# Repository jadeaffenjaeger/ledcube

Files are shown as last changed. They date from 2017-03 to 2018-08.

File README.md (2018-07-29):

# Contents
Codebase and Schematics for an easily extendable LED cube based on the STM32F103 and TPIC6B595 shift registers.

## Structure
The cube uses two types of driver PCBs: One *Level driver*, which activates the anodes for one out of eight levels at a time. The PCB also contains the main MCU on a "Blue Pill" breakout board, as well as voltage regulation for the MCU and 74HCT245 bus driver for 3.3V-5V level conversion.
Four *Row Drivers*, each of which controls the anodes of 16 of 64 columns independently.
All boards are designed to be chained together with the level driver coming first, followed by the row drivers.
This makes it possible to control the cube with just 3 pins on the MCU. All boards are designed to be extendable and reusable for cubes that require more or less contol pins

## Row Driver Boards
The driver board contains two TPIC6B595, capable of controlling a total of 16 outputs with a current sinking capability of 100mA per channel, eliminating the need for external driving transistors. Resistors can be replaced easily to allow for different types of LEDs. The boards are designed to be daisy-chained together, so that larger cubes can be built without redesigning anything, just by adding more driver boards. Also, this easily fills up the minimum order with most board houses. I had mine
manufactured at [Dirty PCBs](www.dirtypcbs.com), where 10 boards cost around 15USD.

Inputs on the board are:

    1 VCC
    2 Serial Clock
    3 Register Clock/Latch
    4 Serial Data
    5 GND

Assembled Board:
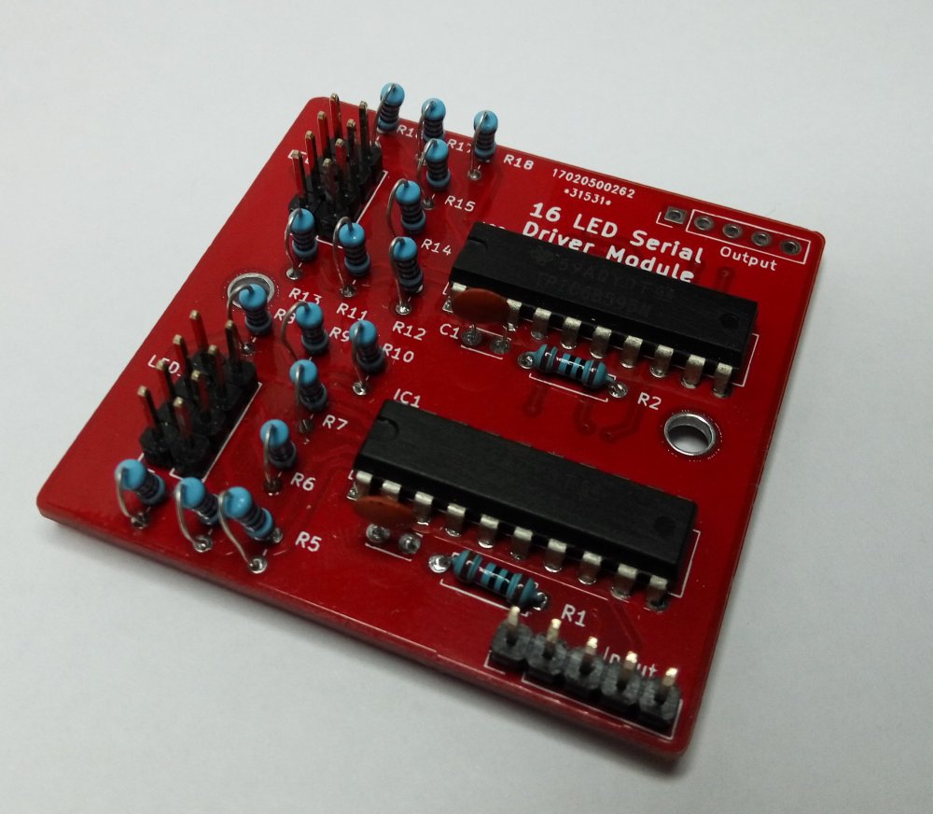
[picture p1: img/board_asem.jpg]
Assembled Driver Board


## Level Driver board
In an earlier iteration, this was a very simple board that only contained the shift register IC and the p-channel MOSFETs. As of now, the board was redesigned to contain the MCU, voltage regulation and the shift register and MOS transistors

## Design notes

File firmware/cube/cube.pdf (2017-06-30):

## cube Project Configuration Report

# 1. Description

## 1.1. Project

Project Name | cube
Board Name | cube
Generated with: | STM32CubeMX 4.21.0
Date | 06/29/2017

## 1.2. MCU

MCU Series | STM32F1
MCU Line | STM32F103
MCU name | STM32F103C8Tx
MCU Package | LQFP48
MCU Pin number | 48

# 2. Pinout Configuration

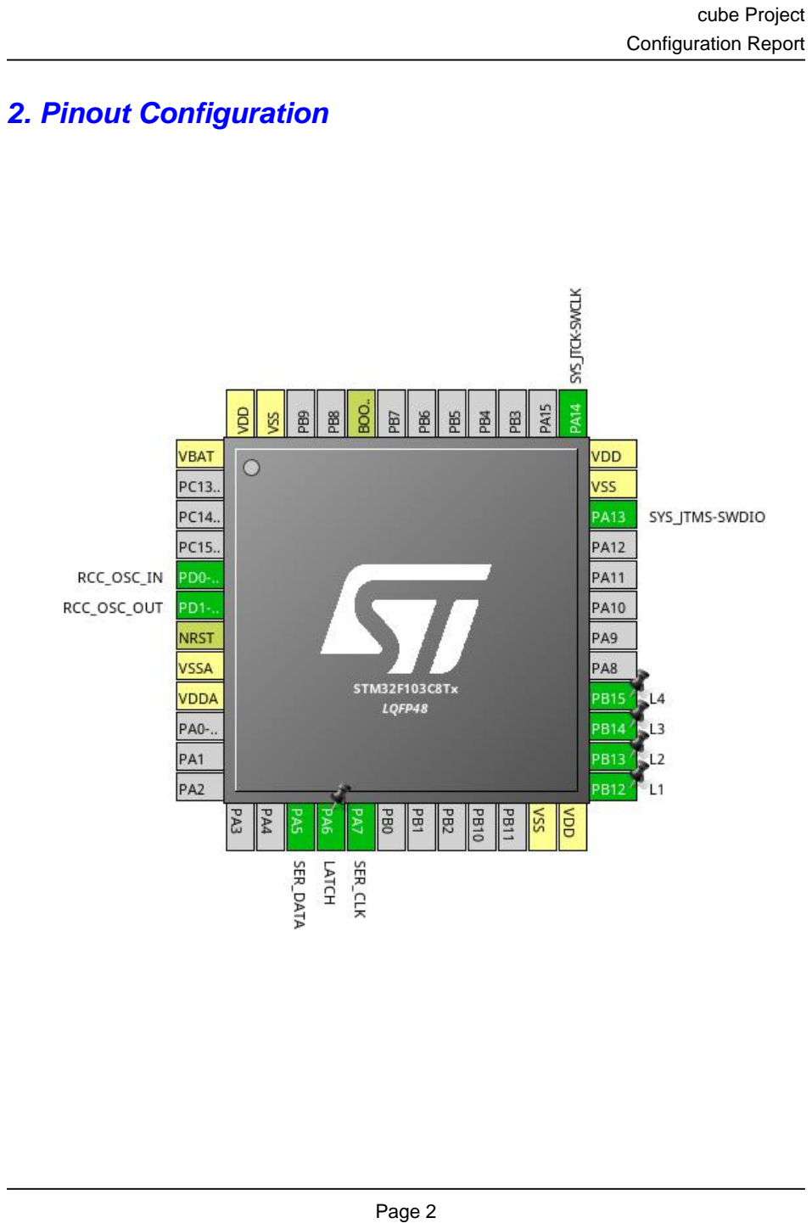
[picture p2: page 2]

# 3. Pins Configuration

Pin Number LQFP48 | Pin Name (function after reset) | Pin Type | Alternate Function(s) | Label
1 | VBAT | Power
5 | PD0-OSC_IN | I/O | RCC_OSC_IN
6 | PD1-OSC_OUT | I/O | RCC_OSC_OUT
7 | NRST | Reset
8 | VSSA | Power
9 | VDDA | Power
15 | PA5 | I/O | SPI1_SCK | SER_DATA
16 | PA6 * | I/O | GPIO_Output | LATCH
17 | PA7 | I/O | SPI1_MOSI | SER_CLK
23 | VSS | Power
24 | VDD | Power
25 | PB12 * | I/O | GPIO_Output | L1
26 | PB13 * | I/O | GPIO_Output | L2
27 | PB14 * | I/O | GPIO_Output | L3
28 | PB15 * | I/O | GPIO_Output | L4
34 | PA13 | I/O | SYS_JTMS-SWDIO
35 | VSS | Power
36 | VDD | Power
37 | PA14 | I/O | SYS_JTCK-SWCLK
44 | BOOT0 | Boot
47 | VSS | Power
48 | VDD | Power

## * The pin is affected with an I/O function

# 4. Clock Tree Configuration

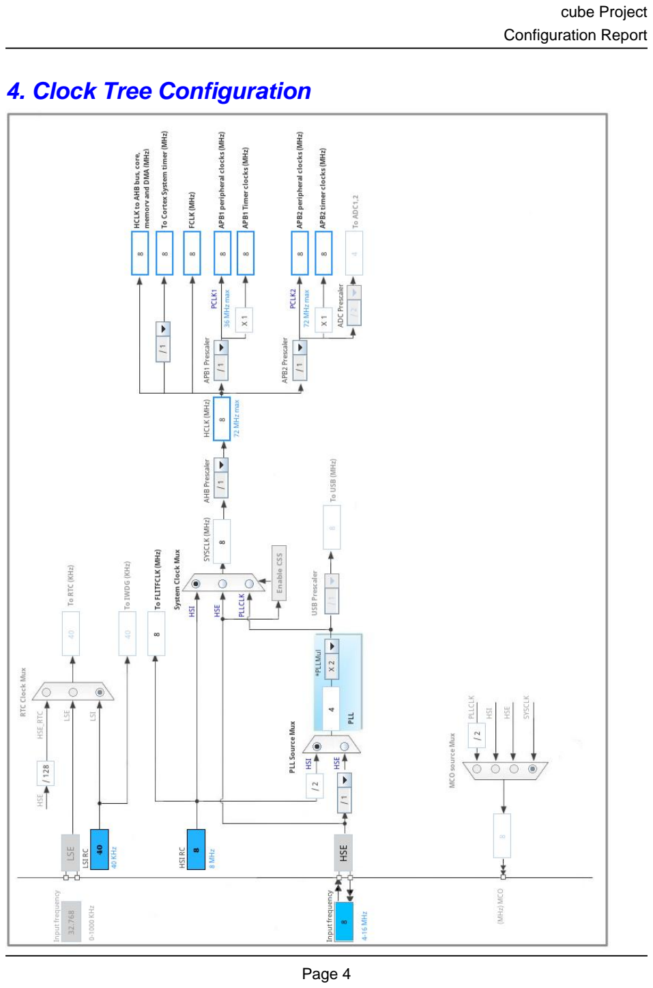
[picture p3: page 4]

# 5. IPs and Middleware Configuration

# 5.1. RCC

## High Speed Clock (HSE): Crystal/Ceramic Resonator

## 5.1.1. Parameter Settings:

### System Parameters:

VDD voltage (V) | 3.3
Prefetch Buffer | Enabled
Flash Latency(WS) | 0 WS (1 CPU cycle)

### RCC Parameters:

HSI Calibration Value | 16
HSE Startup Timout Value (ms) | 100
LSE Startup Timout Value (ms) | 5000

# 5.2. SPI1

## Mode: Transmit Only Master

## 5.2.1. Parameter Settings:

### Basic Parameters:

Frame Format | Motorola
Data Size | 8 Bits
First Bit | MSB First

### Clock Parameters:

Prescaler (for Baud Rate) | 2
Baud Rate | 4.0 MBits/s *
Clock Polarity (CPOL) | Low
Clock Phase (CPHA) | 1 Edge

### Advanced Parameters:

CRC Calculation | Disabled
NSS Signal Type | Software

# 5.3. SYS

## Debug: Serial Wire Timebase Source: SysTick

# 5.4. TIM2

## Clock Source : Internal Clock

## 5.4.1. Parameter Settings:

### Counter Settings:

Prescaler (PSC - 16 bits value) | 0
Counter Mode | Up
Counter Period (AutoReload Register - 16 bits value ) | 0
Internal Clock Division (CKD) | No Division

### Trigger Output (TRGO) Parameters:

Master/Slave Mode | Disable (no sync between this TIM (Master) and its Slaves
Trigger Event Selection | Reset (UG bit from TIMx_EGR)

### * User modified value

# 6. System Configuration

# 6.1. GPIO configuration

IP | Pin | Signal | GPIO mode | GPIO pull/up pull down | Max Speed | User Label
RCC | PD0-OSC_IN | RCC_OSC_IN | n/a | n/a | n/a
| PD1-OSC_OUT | RCC_OSC_OUT | n/a | n/a | n/a
SPI1 | PA5 | SPI1_SCK | Alternate Function Push Pull | n/a | High * | SER_DATA
| PA7 | SPI1_MOSI | Alternate Function Push Pull | n/a | High * | SER_CLK
SYS | PA13 | SYS_JTMS-SWDIO | n/a | n/a | n/a
| PA14 | SYS_JTCK-SWCLK | n/a | n/a | n/a
GPIO | PA6 | GPIO_Output | Output Push Pull | n/a | Low | LATCH
| PB12 | GPIO_Output | Output Push Pull | n/a | Low | L1
| PB13 | GPIO_Output | Output Push Pull | n/a | Low | L2
| PB14 | GPIO_Output | Output Push Pull | n/a | Low | L3
| PB15 | GPIO_Output | Output Push Pull | n/a | Low | L4

# 6.2. DMA configuration

DMA request | Stream | Direction | Priority
SPI1_TX | DMA1_Channel3 | Memory To Peripheral | Low

## SPI1_TX: DMA1_Channel3 DMA request Settings:

Mode: | Normal
Peripheral Increment: | Disable
Memory Increment: | Enable *
Peripheral Data Width: | Byte
Memory Data Width: | Byte

# 6.3. NVIC configuration

Interrupt Table | Enable | Preenmption Priority | SubPriority
Non maskable interrupt | true | 0 | 0
Hard fault interrupt | true | 0 | 0
Memory management fault | true | 0 | 0
Prefetch fault, memory access fault | true | 0 | 0
Undefined instruction or illegal state | true | 0 | 0
System service call via SWI instruction | true | 0 | 0
Debug monitor | true | 0 | 0
Pendable request for system service | true | 0 | 0
System tick timer | true | 0 | 0
DMA1 channel3 global interrupt | true | 0 | 0
TIM2 global interrupt | true | 0 | 0
SPI1 global interrupt | true | 0 | 0
PVD interrupt through EXTI line 16 | unused
Flash global interrupt | unused
RCC global interrupt | unused

### * User modified value

# 7. Power Consumption Calculator report

### 7.1. Microcontroller Selection

Series | STM32F1
Line | STM32F103
MCU | STM32F103C8Tx
Datasheet | 13587_Rev17

### 7.2. Parameter Selection

Temperature | 25
Vdd | 3.3

# 8. Software Project

## 8.1. Project Settings

Name | Value
Project Name | cube
Project Folder | /home/elias/ledcube/firmware/cube
Toolchain / IDE | Makefile
Firmware Package Name and Version | STM32Cube FW_F1 V1.4.0

## 8.2. Code Generation Settings

Name | Value
STM32Cube Firmware Library Package | Copy only the necessary library files
Generate peripheral initialization as a pair of '.c/.h' files | Yes
Backup previously generated files when re-generating | No
Delete previously generated files when not re-generated | Yes
Set all free pins as analog (to optimize the power consumption) | No

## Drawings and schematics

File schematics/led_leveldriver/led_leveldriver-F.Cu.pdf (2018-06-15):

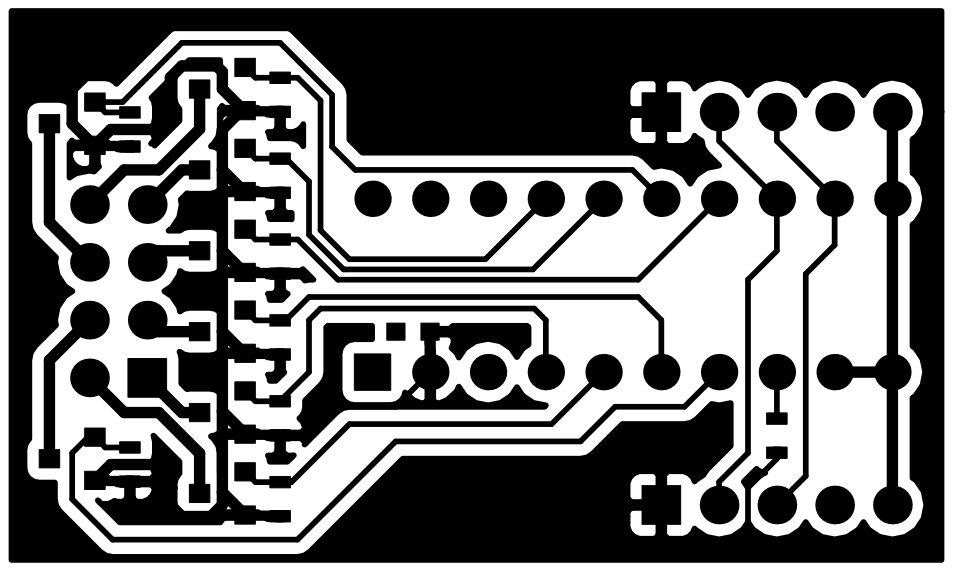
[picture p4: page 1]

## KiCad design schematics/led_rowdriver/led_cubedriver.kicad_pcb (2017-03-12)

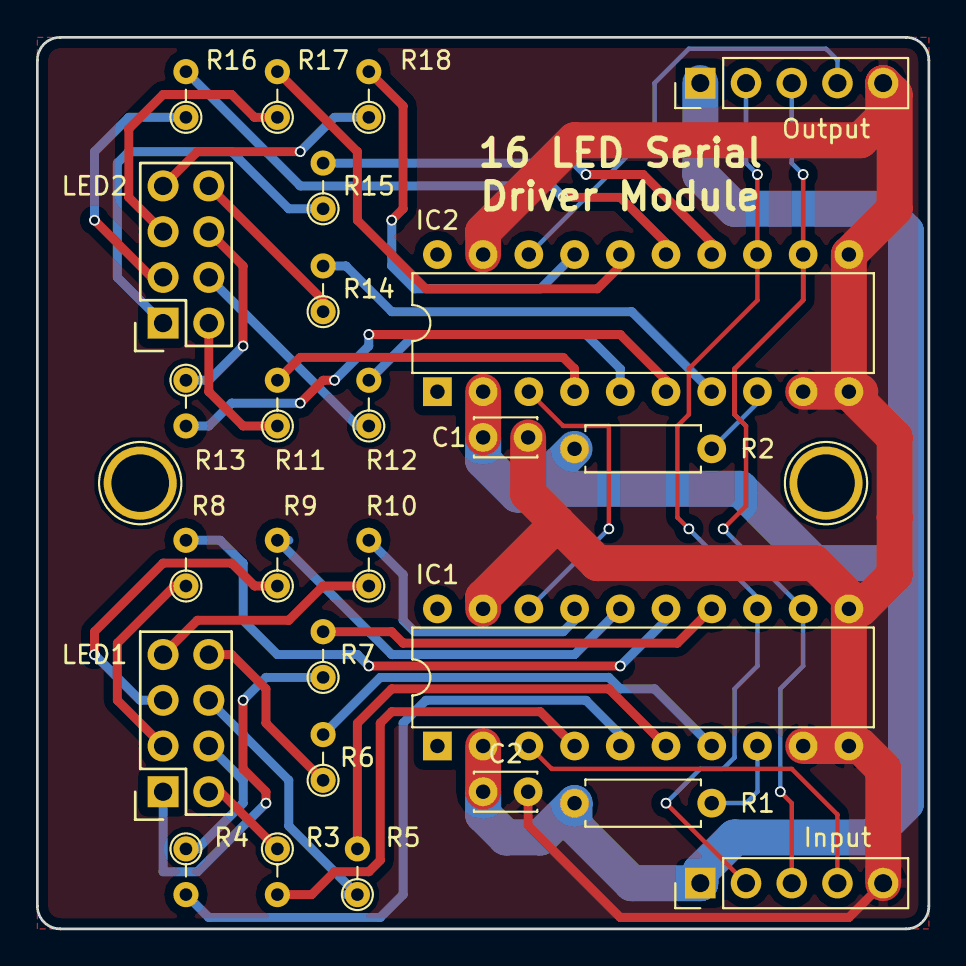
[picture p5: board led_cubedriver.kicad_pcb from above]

Board: 2 copper layers, 49.5 x 49.5 mm, 26 parts (0 on the bottom side), 41 nets.

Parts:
C1, C2: 0.1uF; C_Disc_D3.4mm_W2.1mm_P2.50mm
IC1, IC2: TPIC6B595; DIP-20_W7.62mm
Input: CONN_01X05; Pin_Header_Straight_1x05_Pitch2.54mm
LED1, LED2: CONN_02X04; Socket_Strip_Straight_2x04
Output: CONN_01X05; Pin_Header_Straight_1x05_Pitch2.54mm
R1, R2: 10k; R_Axial_DIN0207_L6.3mm_D2.5mm_P7.62mm_Horizontal
R3, R4, R5, R6, R7, R8, R9, R10, R11, R12, R13, R14, R15, R16, R17, R18: 100; R_Axial_DIN0204_L3.6mm_D1.6mm_P2.54mm_Vertical

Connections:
/RCK: IC1.12, IC2.12, Input.3, Output.3
/SRCK: IC1.13, IC2.13, Input.2, Output.2
GND: C1.2, C2.2, IC1.9, IC1.10, IC1.11, IC1.19, IC2.9, IC2.10, IC2.11, IC2.19, Input.5, Output.5
unnamed: IC1.3, Input.4
unnamed: IC2.18, Output.4
unnamed: IC1.4, R3.2
unnamed: IC1.5, R4.2
unnamed: IC1.6, R5.2
unnamed: IC1.7, R6.2
unnamed: IC1.8, R1.1
unnamed: IC1.14, R7.2
unnamed: IC1.15, R8.2
unnamed: IC1.16, R9.2
unnamed: IC1.17, R10.2
unnamed: IC1.18, IC2.3
unnamed: IC2.4, R11.2
unnamed: IC2.5, R12.2
unnamed: IC2.6, R13.2
unnamed: IC2.7, R14.2
unnamed: IC2.8, R2.1
unnamed: IC2.14, R15.2
unnamed: IC2.15, R16.2
unnamed: IC2.16, R17.2
unnamed: IC2.17, R18.2
unnamed: LED1.1, R7.1
unnamed: LED1.2, R3.1
unnamed: LED1.3, R8.1
unnamed: LED1.4, R4.1
unnamed: LED1.5, R9.1
unnamed: LED1.6, R5.1
unnamed: LED1.7, R10.1
unnamed: LED1.8, R6.1
unnamed: LED2.1, R15.1
unnamed: LED2.2, R11.1
unnamed: LED2.3, R16.1
unnamed: LED2.4, R12.1
unnamed: LED2.5, R17.1
unnamed: LED2.6, R13.1
unnamed: LED2.7, R18.1
unnamed: LED2.8, R14.1
VCC: C1.1, C2.1, IC1.2, IC2.2, Input.1, Output.1, R1.2, R2.2

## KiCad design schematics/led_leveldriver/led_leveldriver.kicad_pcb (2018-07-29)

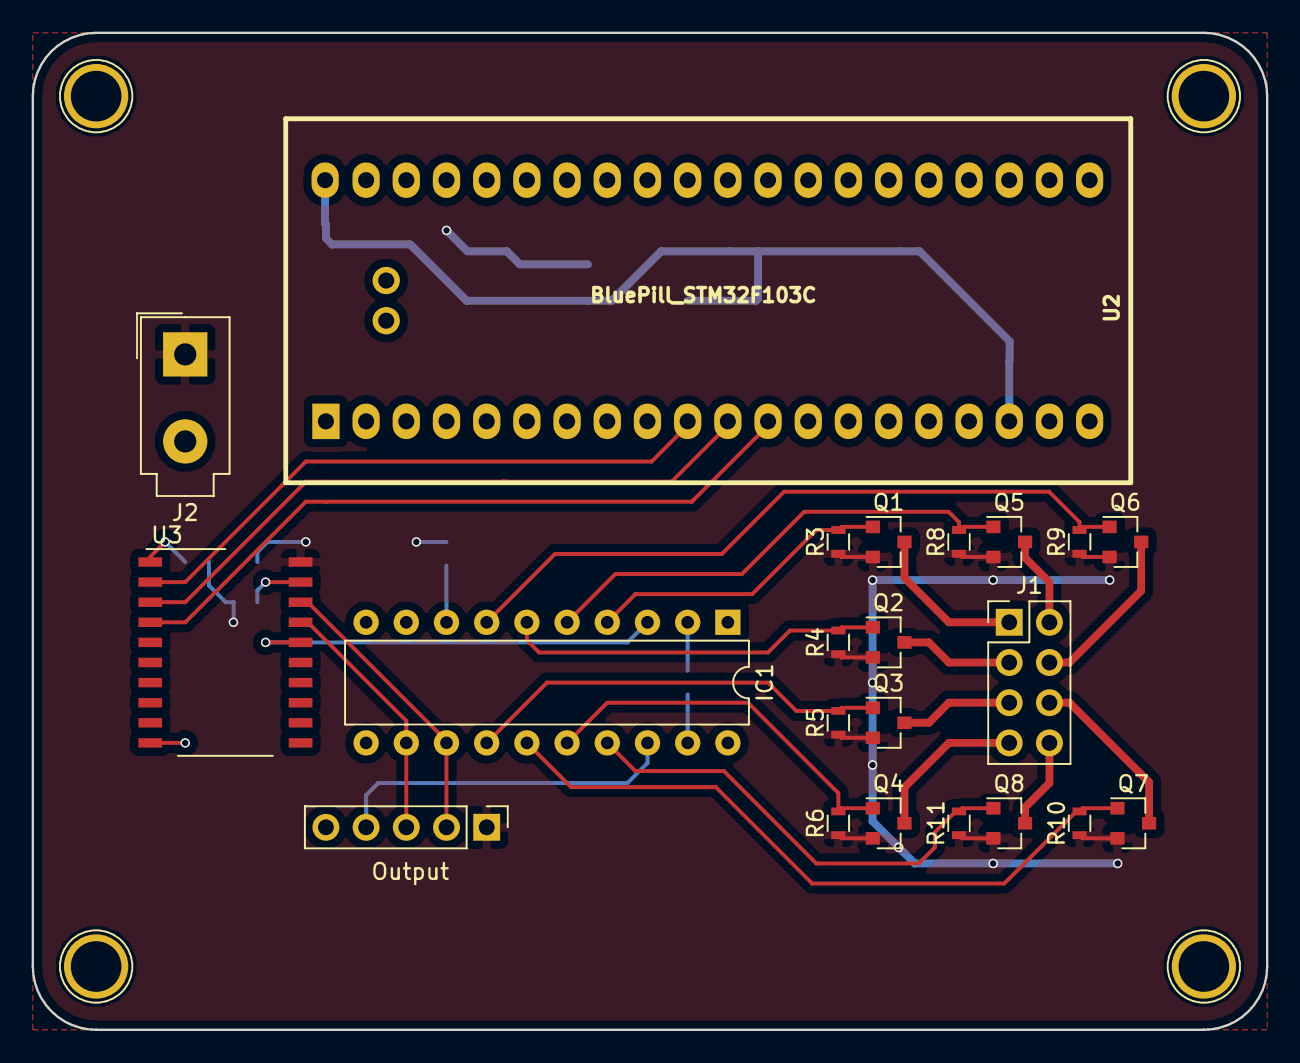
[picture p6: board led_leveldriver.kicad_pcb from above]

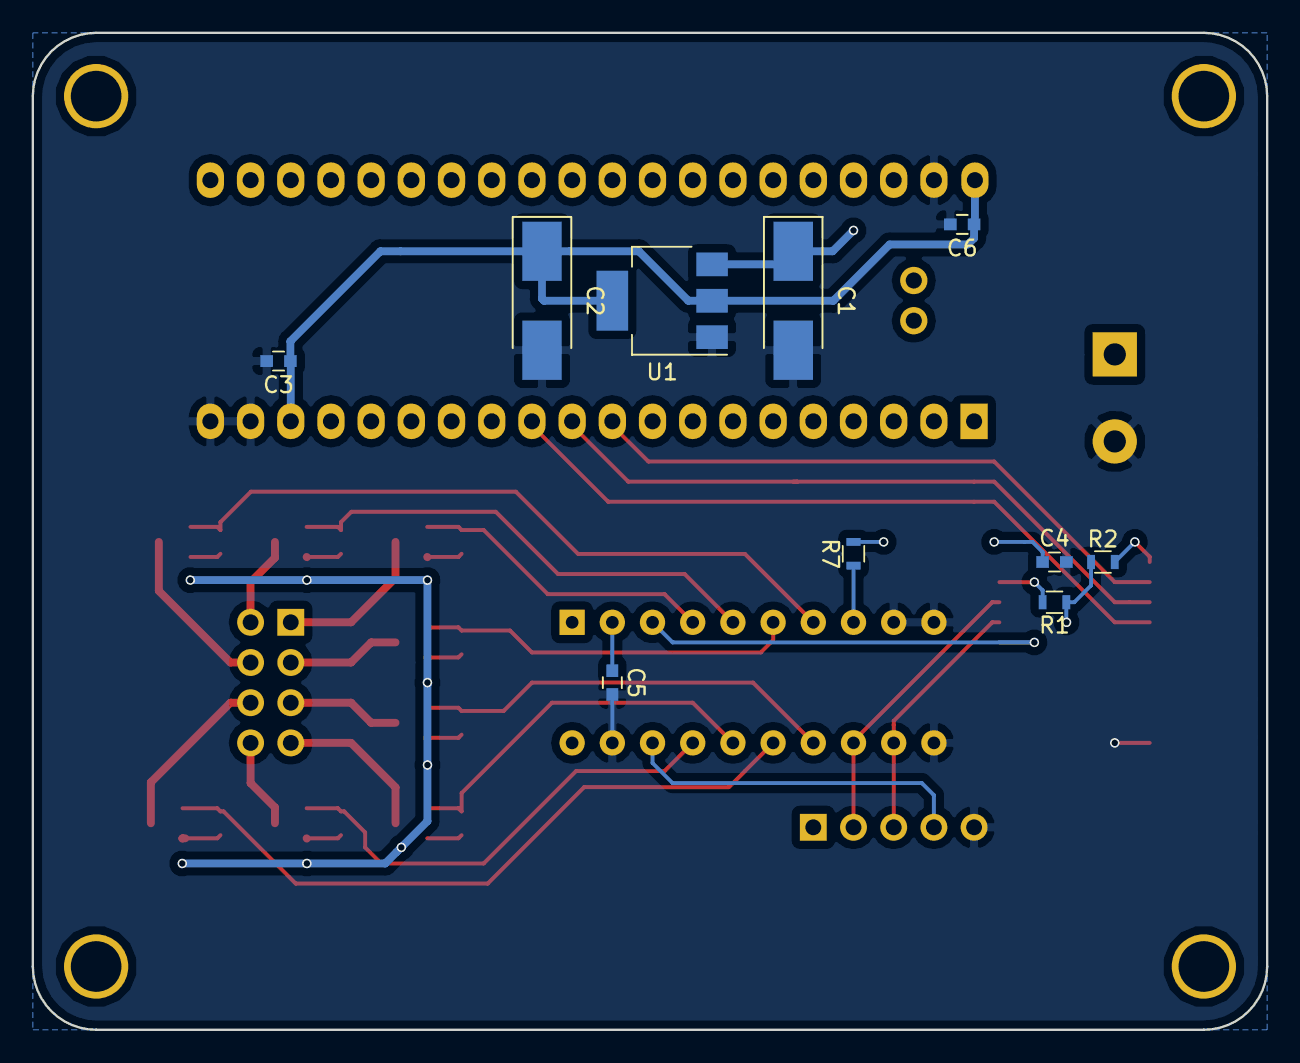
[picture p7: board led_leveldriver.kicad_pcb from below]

Board: 2 copper layers, 78.0 x 63.0 mm, 32 parts (10 on the bottom side), 29 nets.

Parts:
C1, C2: 10u; CP_Tantalum_Case-U_EIA-6032-15_Hand
C3, C4, C5, C6: 0.1uF; C_0603
IC1: TPIC6B595; DIP-20_W7.62mm
J1: Conn_02x04_Odd_Even; Pin_Header_Straight_2x04_Pitch2.54mm
J2: 5V_IN; Molex_MiniFit-JR-5556-02A_2x01x4.20mm_Straight
Output: CONN_01X05; Pin_Header_Straight_1x05_Pitch2.54mm
Q1, Q2, Q3, Q4, Q5, Q6, Q7, Q8: Q_PMOS_GSD; SOT-23
R1, R2, R3, R4, R5, R6, R7, R8, R9, R10, R11: 10k; R_0603
U1: LM1117-3.3; SOT-223-3_TabPin2
U2: BluePill_STM32F103C
U3: 74HCT245; SO-20_12.8x7.5mm_Pitch1.27mm

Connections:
+3V3: C2.1, C3.1, C6.1, U1.2, U2.18, U2.40
/DATA: IC1.3, U3.16
/DOUT: IC1.18, Output.4
/L0: IC1.4, Q1.1, R3.2
/L1: IC1.5, Q5.1, R8.2
/L2: IC1.6, Q2.1, R4.2
/L3: IC1.7, Q6.1, R9.2
/L4: IC1.14, Q3.1, R5.2
/L5: IC1.15, Q7.1, R10.2
/L6: IC1.16, Q4.1, R6.2
/L7: IC1.17, Q8.1, R11.2
/RCK: IC1.12, Output.3, U3.17
/SRCK: IC1.13, Output.2, U3.18
GND: C1.2, C2.2, C3.2, C4.2, C5.2, C6.2, IC1.9, IC1.10, IC1.11, IC1.19, J2.2, Output.5, U1.1, U2.19, U2.20, U2.39, U3.10
unnamed: IC1.8, R7.1
unnamed: J1.1, Q1.3
unnamed: J1.2, Q5.3
unnamed: J1.3, Q2.3
unnamed: J1.4, Q6.3
unnamed: J1.5, Q3.3
unnamed: J1.6, Q7.3
unnamed: J1.7, Q4.3
unnamed: J1.8, Q8.3
unnamed: R1.2, U3.19
unnamed: R2.2, U3.1
unnamed: U2.10, U3.2
unnamed: U2.11, U3.3
unnamed: U2.12, U3.4
VCC: C1.1, C4.1, C5.1, IC1.2, J2.1, Output.1, Q1.2, Q2.2, Q3.2, Q4.2, Q5.2, Q6.2, Q7.2, Q8.2, R1.1, R2.1, R3.1, R4.1, R5.1, R6.1, R7.2, R8.1, R9.1, R10.1, R11.1, U1.3, U3.20

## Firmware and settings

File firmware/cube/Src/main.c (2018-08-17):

/**
 ******************************************************************************
 * @file           : main.c
 * @brief          : Main program body
 ******************************************************************************
 ** This notice applies to any and all portions of this file
 * that are not between comment pairs USER CODE BEGIN and
 * USER CODE END. Other portions of this file, whether 
 * inserted by the user or by software development tools
 * are owned by their respective copyright owners.
 *
 * COPYRIGHT(c) 2018 STMicroelectronics
 *
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
 ******************************************************************************
 */
/* Includes ------------------------------------------------------------------*/
#include "main.h"
#include "stm32f1xx_hal.h"
#include "dma.h"
#include "spi.h"
#include "tim.h"
#include "gpio.h"
#include "animations.h"


/* USER CODE BEGIN PV */

/* USER CODE END PV */

void SystemClock_Config(void);

/* USER CODE BEGIN PFP */

/* USER CODE END PFP */

/**
 * @brief  The application entry point.
 *
 * @retval None
 */
int main(void)
{
    /* MCU Configuration----------------------------------------------------------*/

    /* Reset of all peripherals, Initializes the Flash interface and the Systick. */
    HAL_Init();

    /* Configure the system clock */
    SystemClock_Config();

    /* Initialize all configured peripherals */
    MX_GPIO_Init();
    MX_DMA_Init();
    MX_SPI1_Init();
    MX_TIM4_Init();
    /* USER CODE BEGIN 2 */
    cube_init();
    /* USER CODE END 2 */

    /* Infinite loop */
    /* USER CODE BEGIN WHILE */
    while (1)
    {

        /* USER CODE END WHILE */

        /* USER CODE BEGIN 3 */
        cube_fill(0x0);
        anim_skeleton();
        anim_rainingCubes();
        anim_sine();
        anim_scroll();
        anim_planes();
        for(uint8_t i = 0; i < 10; i++) {
            anim_fallinggrid();
        }
        anim_sineSolid();
        anim_rainingDots();
        anim_sineCenter();


    }
    /* USER CODE END 3 */

}

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


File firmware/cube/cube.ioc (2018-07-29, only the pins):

Mcu.UserName=STM32F103C8Tx
PA13.Signal=SYS_JTMS-SWDIO
PA14.Signal=SYS_JTCK-SWCLK
PA5.Signal=SPI1_SCK
PA6.GPIO_Label=LATCH
PA6.Signal=GPIO_Output
PA7.Signal=SPI1_MOSI
PC13-TAMPER-RTC.GPIO_Label=LED
PC13-TAMPER-RTC.Signal=GPIO_Output
PD0-OSC_IN.Signal=RCC_OSC_IN
PD1-OSC_OUT.Signal=RCC_OSC_OUT

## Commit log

2017-03-12 Add board schematics and readme
    [led_cubedriver.kicad_pcb, led_cubedriver.sch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]
2017-03-18 Add board interface description to README
2017-03-18 Add Board picture and data sheet
2018-05-09 Add PCB layout for level driver
    [led_cubedriver.sch, led_leveldriver.kicad_pcb, led_leveldriver.sch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]
2018-07-28 Restructure Schematics folder
    [led_cubedriver.kicad_pcb, led_cubedriver.sch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]
2018-07-29 Rework Level driver to STM32 breakout board
    [_saved_led_leveldriver.sch, led_leveldriver-2018-07-28-21-13-47.sch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]
2018-07-29 Add animations
    [cube Debug.cfg]

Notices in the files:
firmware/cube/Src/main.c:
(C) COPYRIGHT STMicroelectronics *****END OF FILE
